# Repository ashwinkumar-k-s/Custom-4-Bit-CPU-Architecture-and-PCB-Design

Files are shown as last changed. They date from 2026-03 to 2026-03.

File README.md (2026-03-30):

# Custom 4-Bit CPU Architecture and PCB Design

Designed and simulated a 4-bit microprocessor datapath using discrete logic, including an ALU, program counter, and memory units. Created full schematic and PCB layouts for all individual modules using KiCad, and successfully fabricated and tested the physical ALU board.

## System Architecture

This project implements a rudimentary discrete logic 4-bit processor datapath. The architecture is modularly designed, consisting of the following key components:

### Program Counter (PC)
* 2 Bit Counter using D-Flip Flop to cycle between 4 instructions

### Instruction Memory
* A network of 8 4x1 MUXs to obtain an instruction of 8 bit wide and have 4 instructions at a time loaded.
 8x4_instruction_memory

### 4x4 Memory Unit
* Consists of 4 2x4 Decoders, 4 4-Bit Registers and 4 4x1 MUXs.
* 2x4 Decoder : Used to load values into the register, controlled using Enable signals while in write mode.
* 4-Bit Register: Receives data from Decoders, interconnected as, all Bit-0s from decoder to Register-1, all Bit-1s from decoder to Register-2, all Bit-2s from decoder to Register-3, all Bit-3s from decoder to Register-4.
* 4x1 MUX: Used to read data from the register when in read mode, similar interconnect network as instruction memory.
  4x4_memory_unit

### Operand controller
* Complementary pair of Tri-State Buffers connected to both Registers containing operand A and B
  operand selector

### Arithmetic Logic Unit (ALU)
* Could do 7 operations AND, OR, XOR, ADD, SUB, ROR, ROL.
* AND, OR, XOR operations are directly computed from the received inputs directly using dedicated ICs.
* ADD and SUB is done in a single circuit consisting of 2 Full adders and a XOR IC, where ADD = A+B and SUB = A + 2's complement(B).
* Rotate operations ROR (right) and ROL (left) is done with a 4-bit barrel shifter(used to shift in a single clock cycle).
  4_bit_alu

### Output Control Unit
* All the outputs are simultaneouslly calculated in the ALU,
* Each output is 4-Bit wide and is connected to a dedicated set of 4-Bit Tri-state buffers controlled using a 3x8 Decoder to output the desired value.
  <br>
  output_control_unit

---

## Tools & Technologies

* **Logic Simulation:** Cedar Logic
* **Schematic Capture & PCB Layout:** KiCad
* **Hardware:** Discrete logic ICs, custom fabricated PCB

---

## Hardware Implementation & PCB Design

All functional modules were modeled, schematized, and routed as individual PCBs. The ALU module was fabricated in PCB and the rest were validated in breadboard circuitry.

### Hardware implementation of 4x4 Memory unit 

<br>

* 4 4x1 MUXs - 74LS153.
* 4 4-Bit Registers - 74LS173.
* 4 2x4 Decoder - 74LS139.
<br>


<br>

### Hardware implementation of Memory Data Register (Operand Selector)

<br>

* 3 4-Bit Registers - 74LS173.
* 1 8xTri-State Buffers - 74LS244.
* 1x2 Decoder made using AND and NOT ICs.

### ALU implementaion in PCB
alu pcb_re
<br>

* AND - 7408.
* OR - 7432.
* XOR - 7486.
* 4-Bit Full Adder - 7483.
* 4x1 MUX - 74153.
<br>


<br>

### Output Control Unit
output control
<br>

* 3x8 Decoder - 74138.
* 7 4-Bit Registers - 74173.
<br>

alu_full

<br>

### KiCad PCB Layouts

<br>


<br>

* PCB Layout of Memory Unit
<br>


<br>


<br>

* PCB layout of ALU
<br>


<br>


<br>

* PCB layout of Output Control Unit

### Cedar Logic Simulation
4-bit cpu
<br>

---

## Repository Structure

```text
├── simulations/          # Cedar Logic simulation files
│   ├── full_layout 
├── kicad_projects/       # KiCad schematics and PCB layout files
│   ├── Output_control_unit/
│   ├── ALU_module/
│   └── 4x4_Memory_Unit/     
└── README.md
 ```

## Contributors

This 4-bit CPU architecture and PCB design project was collaboratively developed as an assigned group project. 

* **[Adithya Balesh (CB.EN.U4ECE23005)/adithyabalesh]** - *Digital Design and Hardware Verification and PCB*
  * Instruction Memory and Component Integration and verification.
  * Hardware Implementation of Output control unit and ALU.
  * PCB routing and layout arrangement of memory.
  * Poster and Documentation.

* **[Ashwin Kumar K S (CB.EN.U4ECE23007)/ashwinkumar-k-s]** - *ALU Design and PCB routing,hardware impllementaion*
  * ALU, Output Control Unit and Datapath design.
  * Component Selection and Hardware implementation of ALU and Memory data register.
  * PCB routing, layout, and schematic generation of ALU and Output control Unit 
  * Documentation and Github Repo Creation.
  
* **[Chokkalingam S (CB.EN.U4ECE23012)/-------]** - *Memory Design and hardware impllementaion*
  * Digital design of 4x4 Memory Unit,  Memory Data Register Design and Pipeline/Interconnects accross all modules.
  * Hardware implementation and verification of Memory module and Instruction Memory.
  * PCB schematic of Memory module.
  * Documentation.

* **[Rohith J (CB.EN.U4ECE23017)/-------]** - *Digital Design and Hardware Verification*
  * Digital design verification of all components.
  * Hardware circuit implementation of and Memory Units.
  * PCB schematic verification and soldering.
  * Poster, Presentation and Documentation

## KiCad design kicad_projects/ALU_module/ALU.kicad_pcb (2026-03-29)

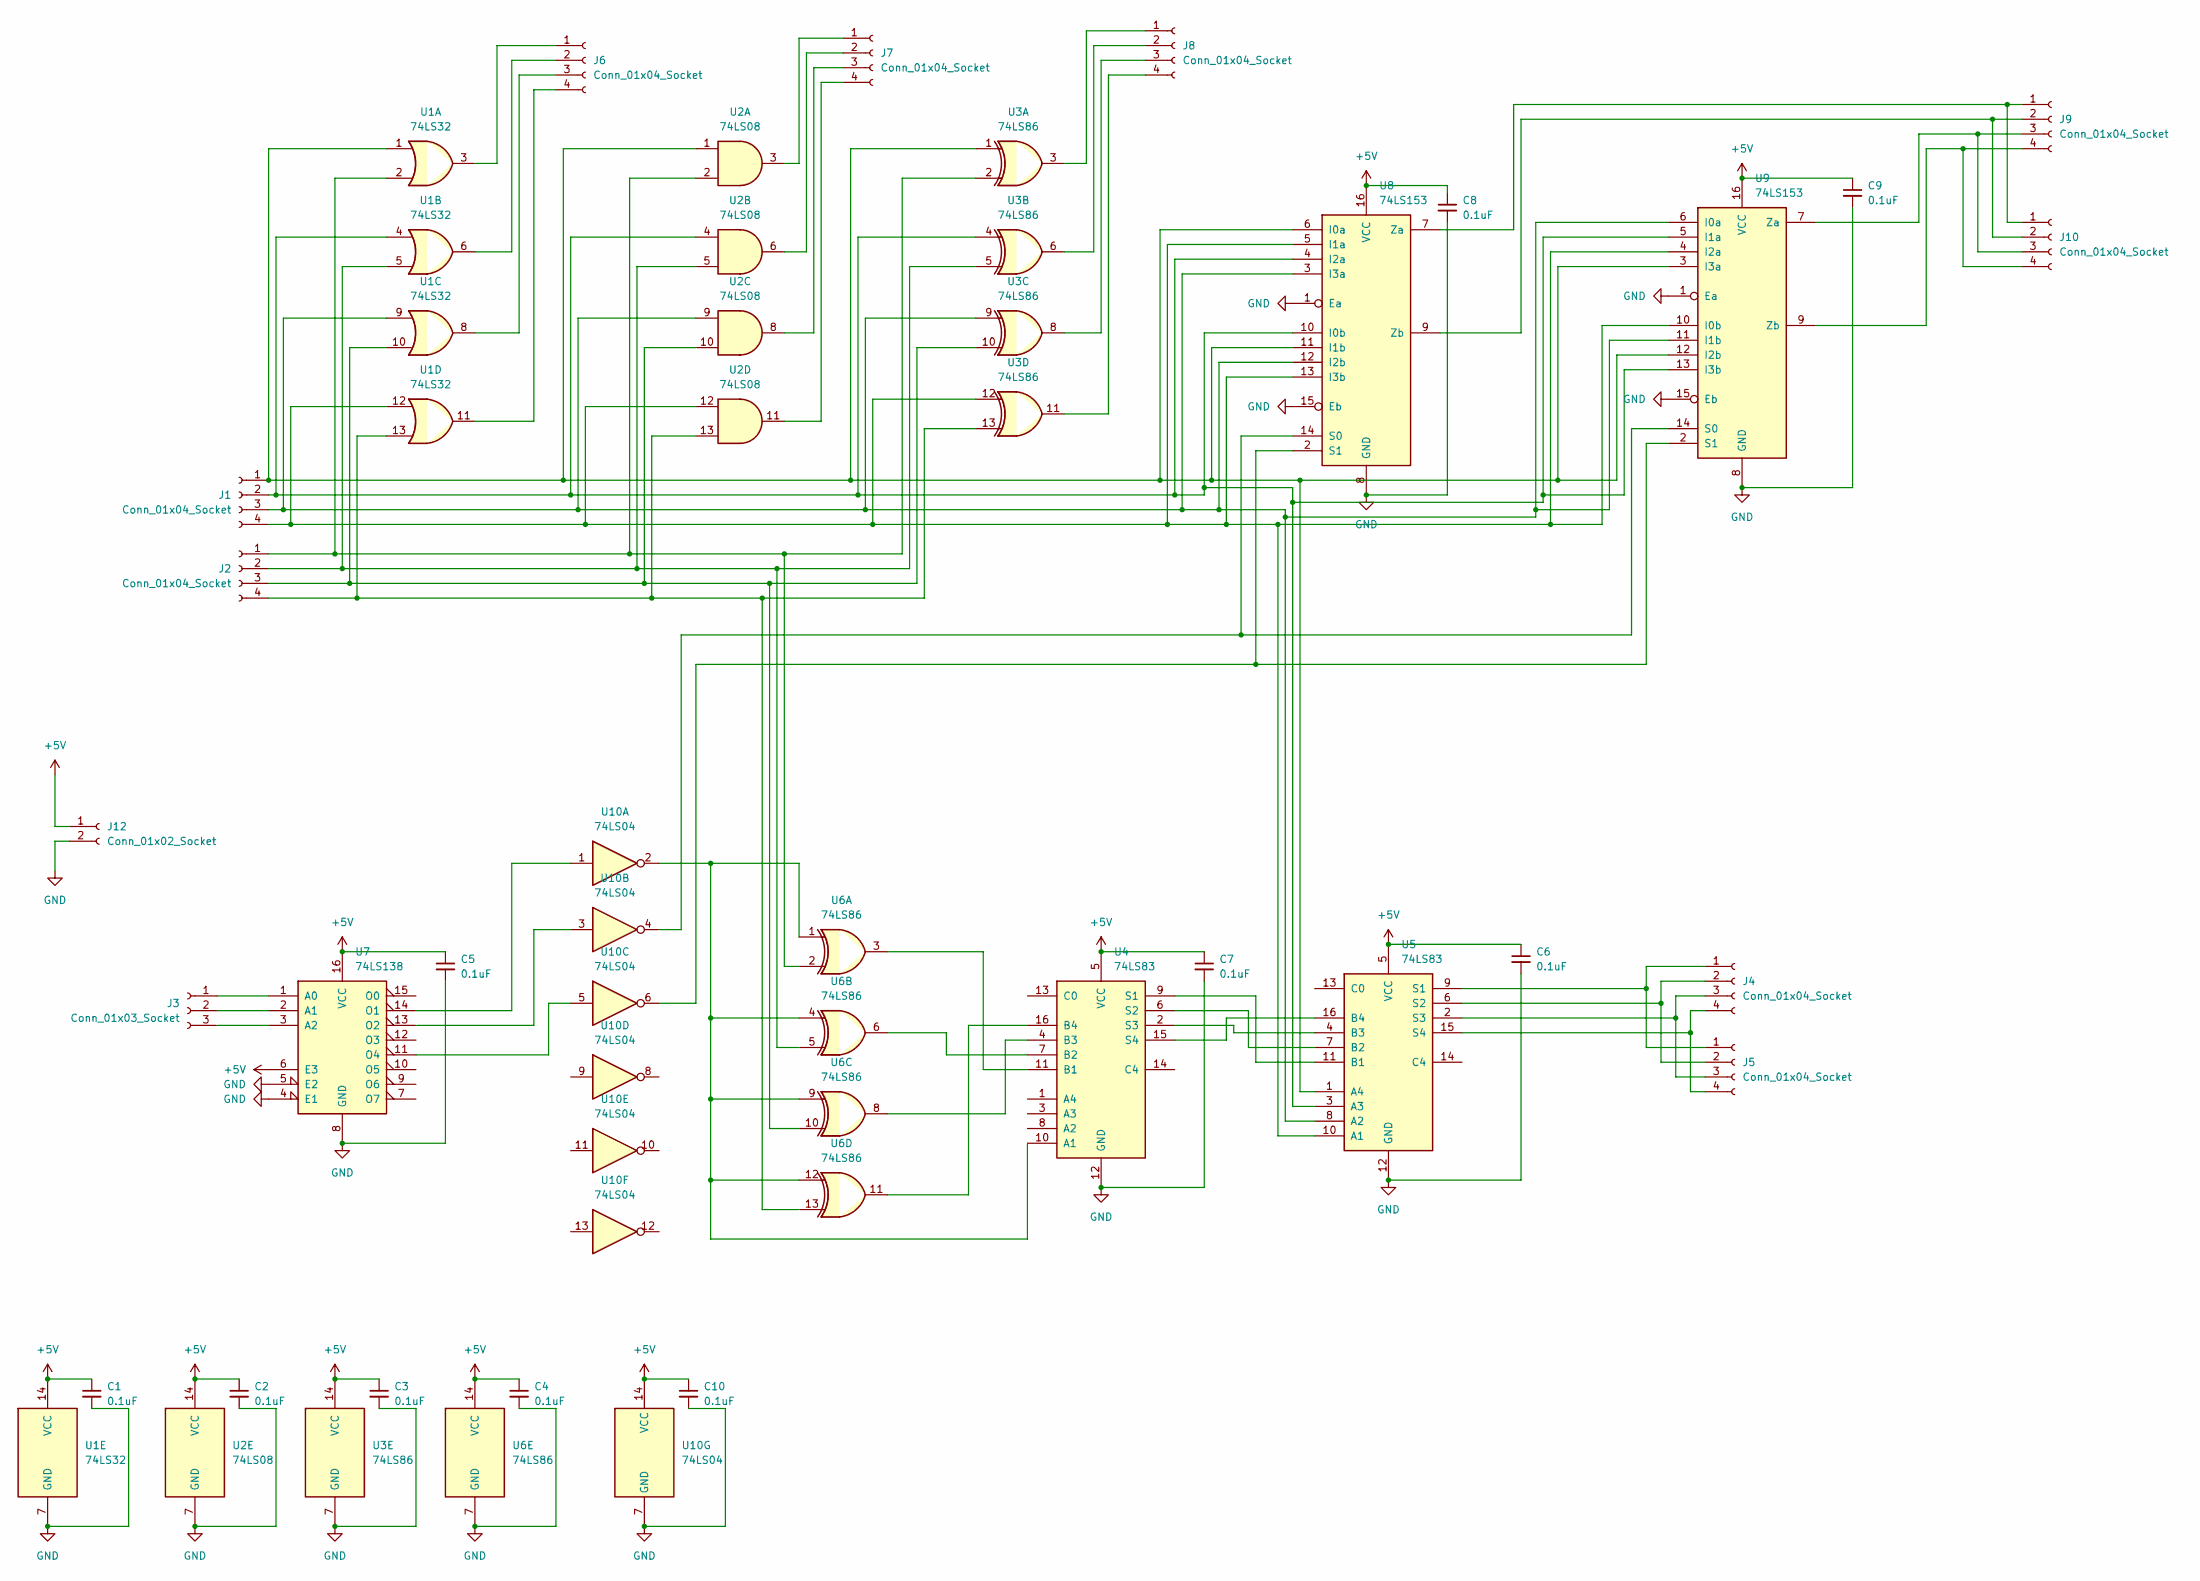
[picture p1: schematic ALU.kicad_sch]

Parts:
C1, C2, C3, C4, C5, C6, C7, C8, C9, C10: 0.1uF; C_Disc_D5.0mm_W2.5mm_P2.50mm
J1, J2, J4, J5, J6, J7, J8, J9, J10: Conn_01x04_Socket; PinSocket_1x04_P2.54mm_Vertical
J3: Conn_01x03_Socket; PinSocket_1x03_P2.54mm_Vertical
J12: Conn_01x02_Socket; PinSocket_1x02_P2.54mm_Vertical
U1: 74LS32; DIP-14_W7.62mm_LongPads
U2: 74LS08; DIP-14_W7.62mm_LongPads
U3, U6: 74LS86; DIP-14_W7.62mm_LongPads
U4, U5: 74LS83; DIP-16_W7.62mm_LongPads
U7: 74LS138; DIP-16_W7.62mm_LongPads
U8, U9: 74LS153; DIP-16_W7.62mm_LongPads
U10: 74LS04; DIP-14_W7.62mm_LongPads

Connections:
+5V: C1.1, C2.1, C3.1, C4.1, C5.1, C6.1, C7.1, C8.1, C9.1, C10.1, J12.1, U1.14 (VCC), U2.14 (VCC), U3.14 (VCC), U4.5 (VCC), U5.5 (VCC), U6.14 (VCC), U7.6 (E3), U7.16 (VCC), U8.16 (VCC), U9.16 (VCC), U10.14 (VCC)
GND: C1.2, C2.2, C3.2, C4.2, C5.2, C6.2, C7.2, C8.2, C9.2, C10.2, J12.2, U1.7 (GND), U2.7 (GND), U3.7 (GND), U4.12 (GND), U5.12 (GND), U6.7 (GND), U7.4 (E1), U7.5 (E2), U7.8 (GND), U8.1 (Ea), U8.8 (GND), U8.15 (Eb), U9.1 (Ea), U9.8 (GND), U9.15 (Eb), U10.7 (GND)
unnamed: J1.1, U1.1, U2.1, U3.1, U5.1 (A4), U8.6 (I0a), U8.11 (I1b), U9.3 (I3a), U9.12 (I2b)
unnamed: J1.2, U1.4, U2.4, U3.4, U5.3 (A3), U8.4 (I2a), U8.10 (I0b), U9.5 (I1a), U9.13 (I3b)
unnamed: J1.3, U1.9, U2.9, U3.9, U5.8 (A2), U8.3 (I3a), U8.12 (I2b), U9.6 (I0a), U9.11 (I1b)
unnamed: J1.4, U1.12, U2.12, U3.12, U5.10 (A1), U8.5 (I1a), U8.13 (I3b), U9.4 (I2a), U9.10 (I0b)
unnamed: J2.1, U1.2, U2.2, U3.2, U6.2
unnamed: J2.2, U1.5, U2.5, U3.5, U6.5
unnamed: J2.3, U1.10, U2.10, U3.10, U6.10
unnamed: J2.4, U1.13, U2.13, U3.13, U6.13
unnamed: J3.1, U7.1 (A0)
unnamed: J3.2, U7.2 (A1)
unnamed: J3.3, U7.3 (A2)
unnamed: J4.1, J5.1, U5.9 (S1)
unnamed: J4.2, J5.2, U5.6 (S2)
unnamed: J4.3, J5.3, U5.2 (S3)
unnamed: J4.4, J5.4, U5.15 (S4)
unnamed: J6.1, U1.3
unnamed: J6.2, U1.6
unnamed: J6.3, U1.8
unnamed: J6.4, U1.11
unnamed: J7.1, U2.3
unnamed: J7.2, U2.6
unnamed: J7.3, U2.8
unnamed: J7.4, U2.11
unnamed: J8.1, U3.3
unnamed: J8.2, U3.6
unnamed: J8.3, U3.8
unnamed: J8.4, U3.11
unnamed: J9.1, J10.1, U8.7 (Za)
unnamed: J9.2, J10.2, U8.9 (Zb)
unnamed: J9.3, J10.3, U9.7 (Za)
unnamed: J9.4, J10.4, U9.9 (Zb)
unnamed: U4.10 (A1), U6.1, U6.4, U6.9, U6.12, U10.2
unnamed: U4.11 (B1), U6.3
unnamed: U4.7 (B2), U6.6
unnamed: U4.4 (B3), U6.8
unnamed: U4.16 (B4), U6.11
unnamed: U4.9 (S1), U5.11 (B1)
unnamed: U4.6 (S2), U5.7 (B2)
unnamed: U4.2 (S3), U5.4 (B3)
unnamed: U4.15 (S4), U5.16 (B4)
unnamed: U7.14 (O1), U10.1
unnamed: U7.13 (O2), U10.3
unnamed: U7.11 (O4), U10.5
unnamed: U8.14 (S0), U9.14 (S0), U10.4
unnamed: U8.2 (S1), U9.2 (S1), U10.6

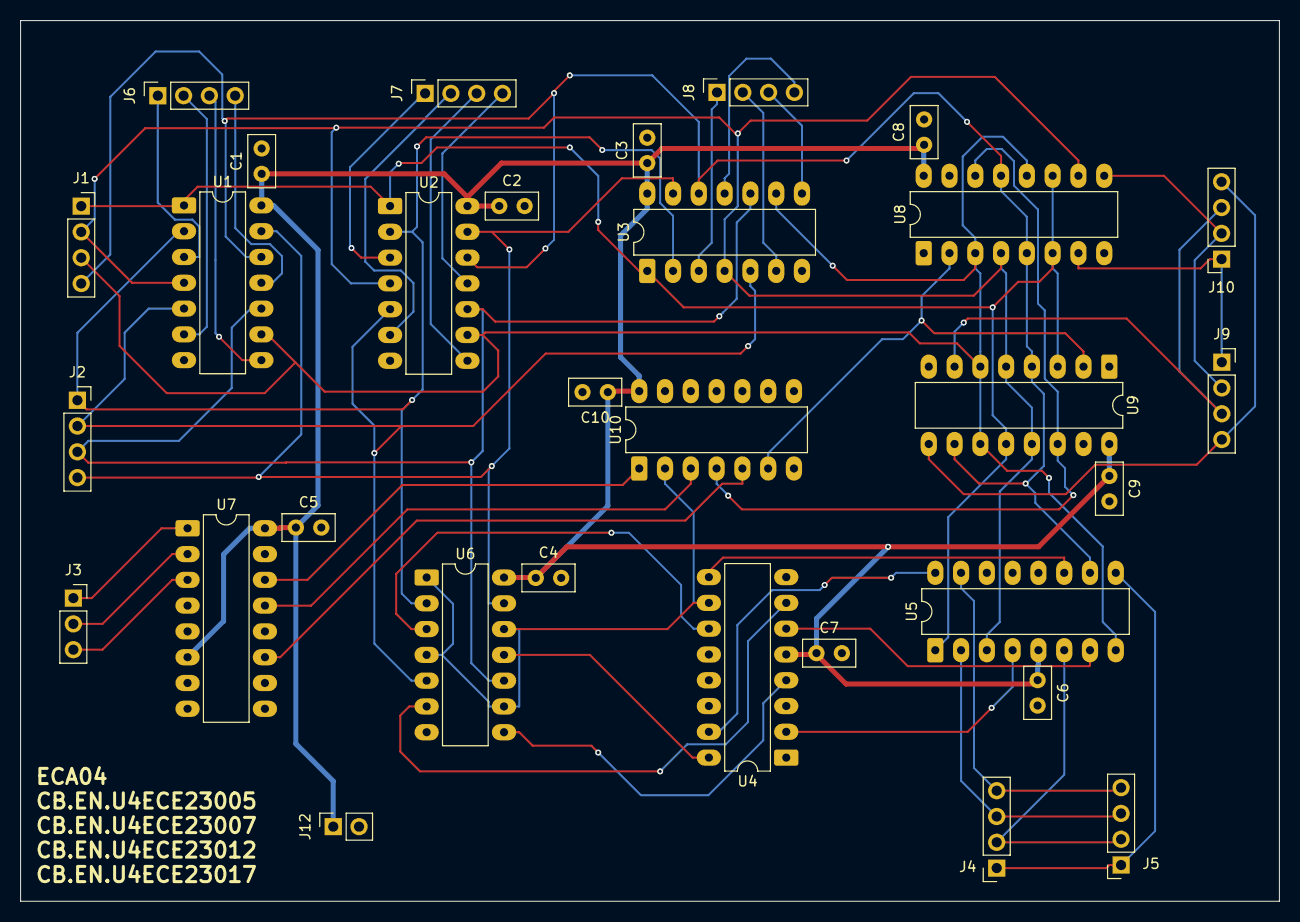
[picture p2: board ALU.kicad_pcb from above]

Board: 2 copper layers, 124.0 x 86.8 mm, 31 parts (0 on the bottom side), 47 nets.

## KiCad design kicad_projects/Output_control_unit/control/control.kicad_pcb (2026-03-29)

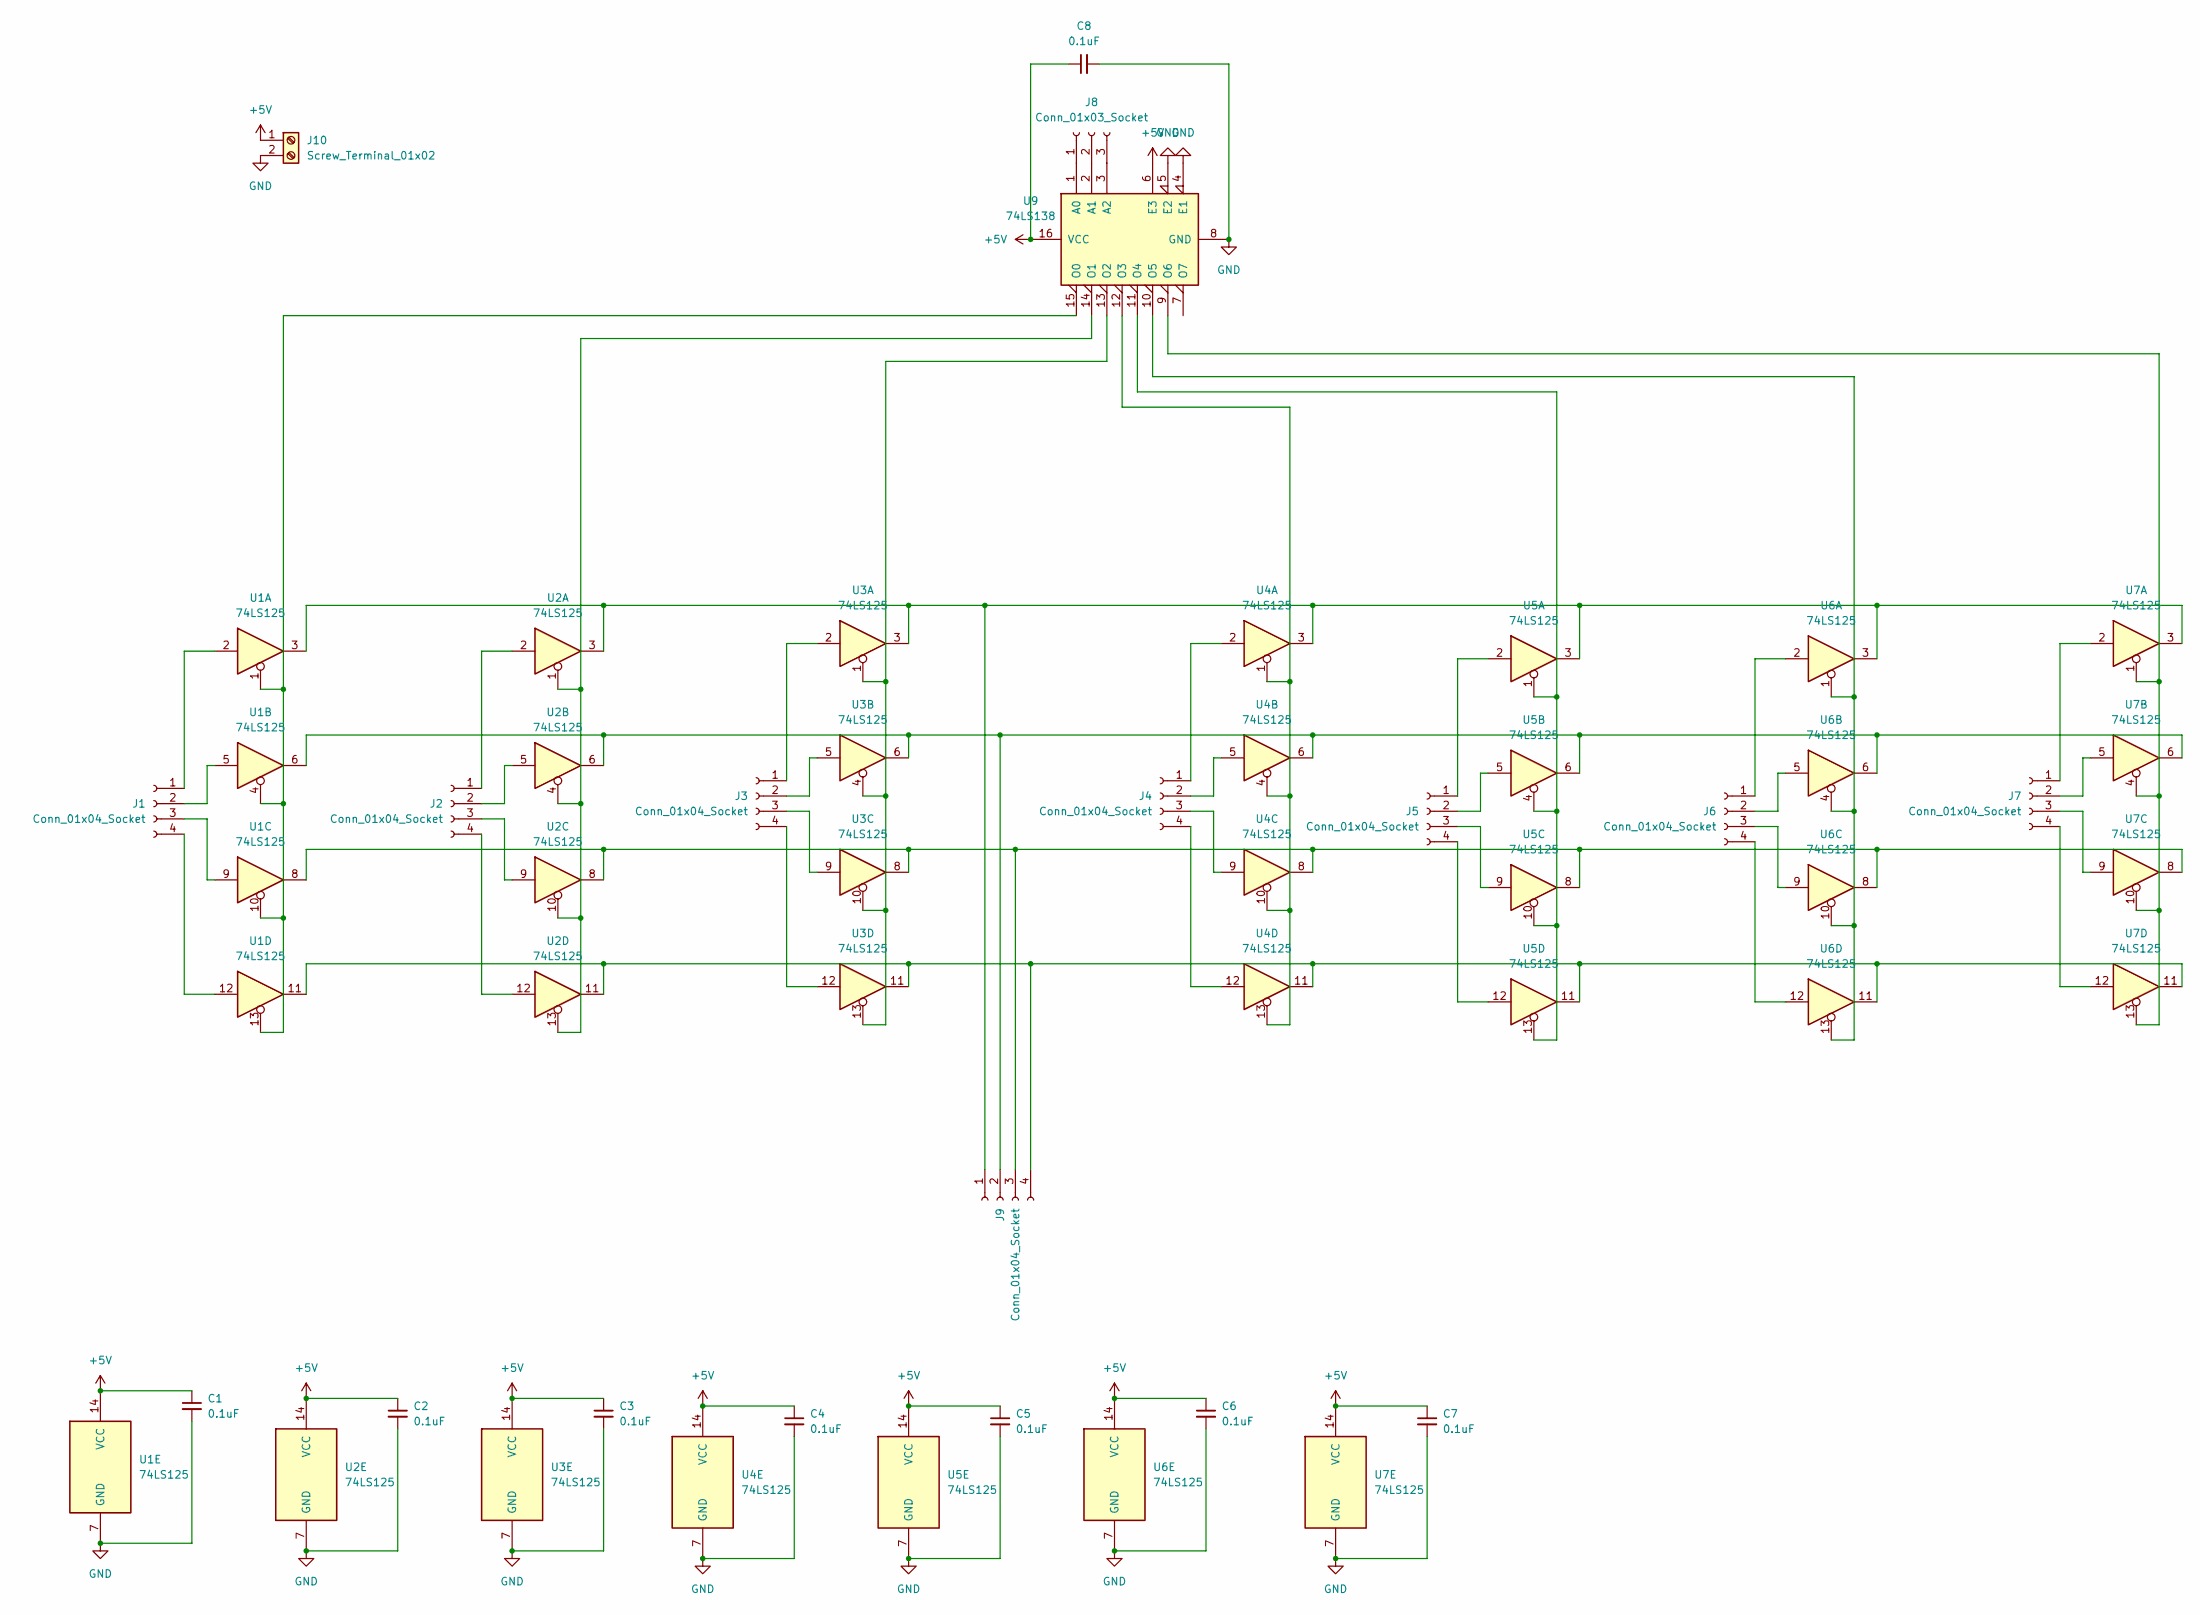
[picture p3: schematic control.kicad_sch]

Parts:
C1, C2, C3, C4, C5, C6, C7, C8: 0.1uF; C_Disc_D5.0mm_W2.5mm_P2.50mm
J1, J2, J3, J4, J5, J6, J7, J9: Conn_01x04_Socket; PinSocket_1x04_P2.54mm_Vertical
J8: Conn_01x03_Socket; PinSocket_1x03_P2.54mm_Vertical
J10: Screw_Terminal_01x02; TerminalBlock_MetzConnect_Type094_RT03502HBLU_1x02_P5.00mm_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
U1, U2, U3, U4, U5, U6, U7: 74LS125; DIP-14_W7.62mm_LongPads
U9: 74LS138; DIP-16_W7.62mm_LongPads

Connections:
+5V: C1.1, C2.1, C3.1, C4.1, C5.1, C6.1, C7.1, C8.1, J10.1, U1.14 (VCC), U2.14 (VCC), U3.14 (VCC), U4.14 (VCC), U5.14 (VCC), U6.14 (VCC), U7.14 (VCC), U9.6 (E3), U9.16 (VCC)
GND: C1.2, C2.2, C3.2, C4.2, C5.2, C6.2, C7.2, C8.2, J10.2, U1.7 (GND), U2.7 (GND), U3.7 (GND), U4.7 (GND), U5.7 (GND), U6.7 (GND), U7.7 (GND), U9.4 (E1), U9.5 (E2), U9.8 (GND)
unnamed: J1.1, U1.2
unnamed: J1.2, U1.5
unnamed: J1.3, U1.9
unnamed: J1.4, U1.12
unnamed: J2.1, U2.2
unnamed: J2.2, U2.5
unnamed: J2.3, U2.9
unnamed: J2.4, U2.12
unnamed: J3.1, U3.2
unnamed: J3.2, U3.5
unnamed: J3.3, U3.9
unnamed: J3.4, U3.12
unnamed: J4.1, U4.2
unnamed: J4.2, U4.5
unnamed: J4.3, U4.9
unnamed: J4.4, U4.12
unnamed: J5.1, U5.2
unnamed: J5.2, U5.5
unnamed: J5.3, U5.9
unnamed: J5.4, U5.12
unnamed: J6.1, U6.2
unnamed: J6.2, U6.5
unnamed: J6.3, U6.9
unnamed: J6.4, U6.12
unnamed: J7.1, U7.2
unnamed: J7.2, U7.5
unnamed: J7.3, U7.9
unnamed: J7.4, U7.12
unnamed: J8.1, U9.1 (A0)
unnamed: J8.2, U9.2 (A1)
unnamed: J8.3, U9.3 (A2)
unnamed: J9.1, U1.3, U2.3, U3.3, U4.3, U5.3, U6.3, U7.3
unnamed: J9.2, U1.6, U2.6, U3.6, U4.6, U5.6, U6.6, U7.6
unnamed: J9.3, U1.8, U2.8, U3.8, U4.8, U5.8, U6.8, U7.8
unnamed: J9.4, U1.11, U2.11, U3.11, U4.11, U5.11, U6.11, U7.11
unnamed: U1.1, U1.4, U1.10, U1.13, U9.15 (O0)
unnamed: U2.1, U2.4, U2.10, U2.13, U9.14 (O1)
unnamed: U3.1, U3.4, U3.10, U3.13, U9.13 (O2)
unnamed: U4.1, U4.4, U4.10, U4.13, U9.12 (O3)
unnamed: U5.1, U5.4, U5.10, U5.13, U9.11 (O4)
unnamed: U6.1, U6.4, U6.10, U6.13, U9.10 (O5)
unnamed: U7.1, U7.4, U7.10, U7.13, U9.9 (O6)

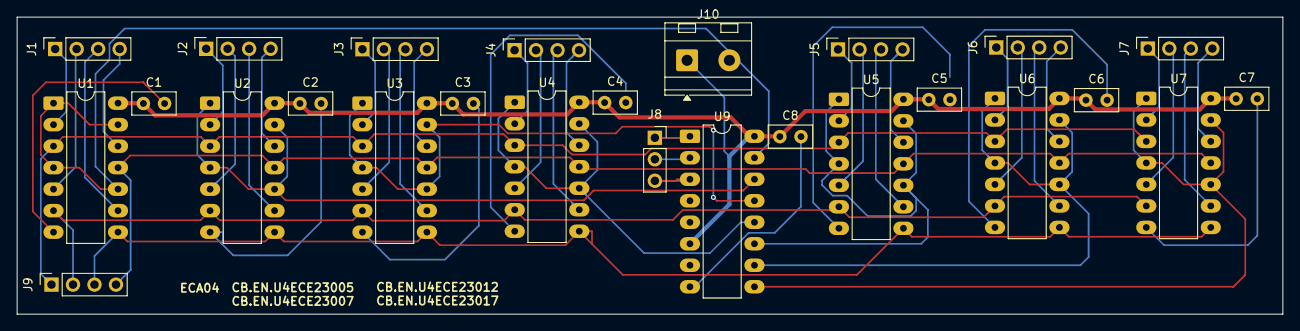
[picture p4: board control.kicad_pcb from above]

Board: 2 copper layers, 149.6 x 35.1 mm, 26 parts (0 on the bottom side), 44 nets.

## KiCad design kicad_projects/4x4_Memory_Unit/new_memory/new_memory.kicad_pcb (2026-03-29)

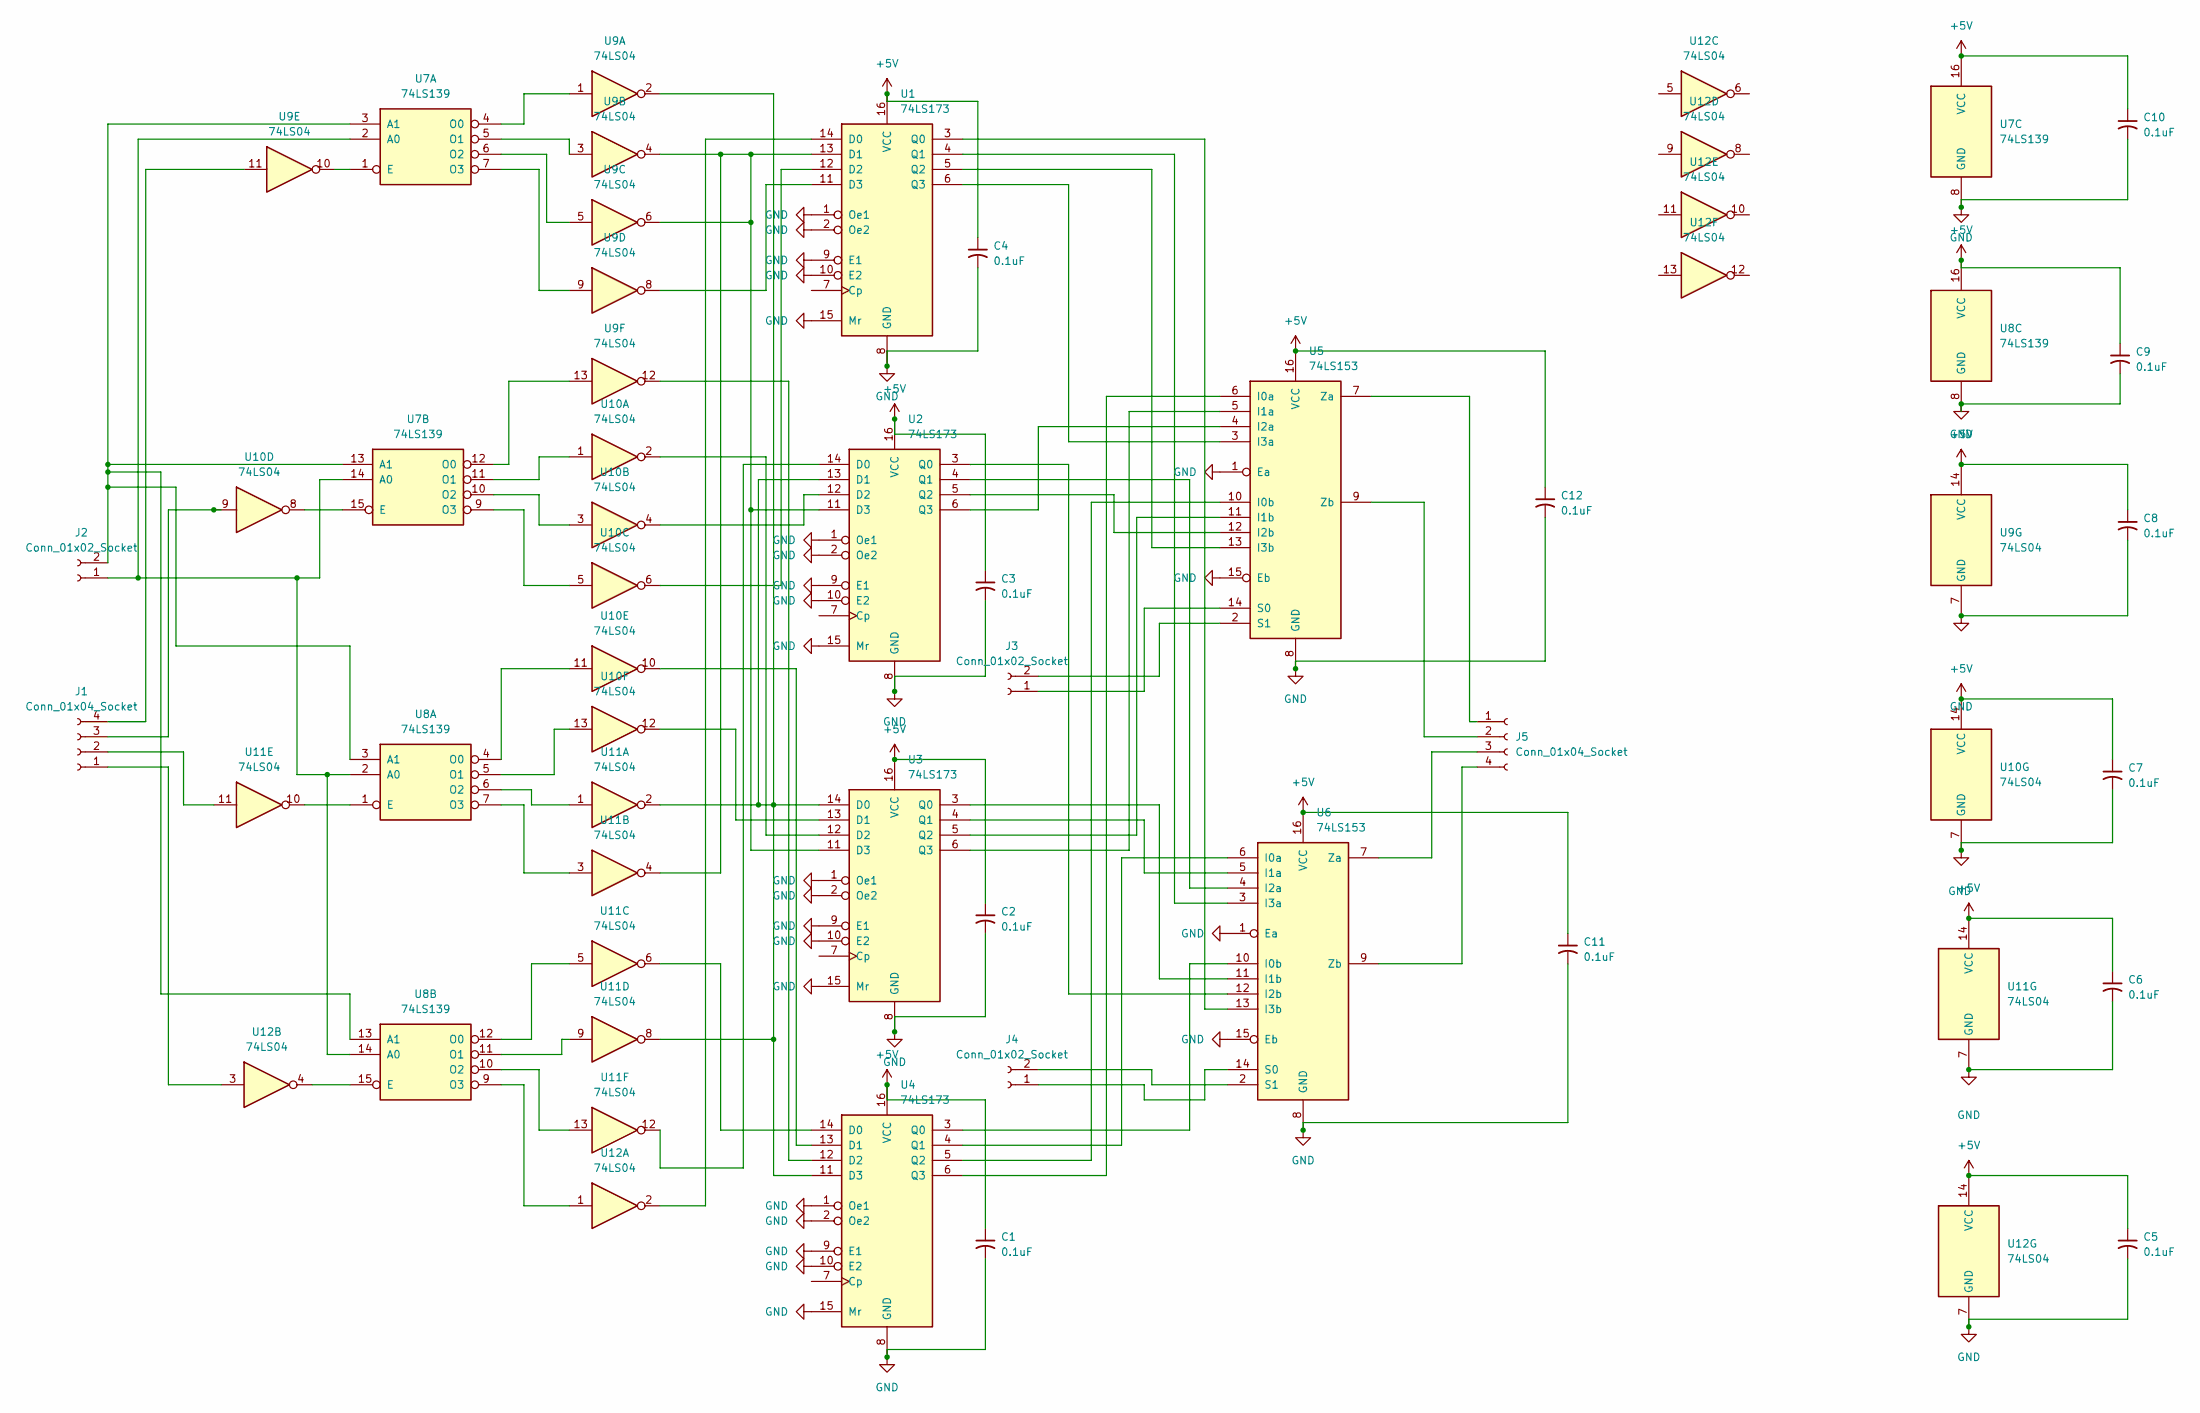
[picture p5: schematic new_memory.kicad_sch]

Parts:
C1, C2, C3, C4, C5, C6, C7, C8, C9, C10, C11, C12: 0.1uF; C_Disc_D5.0mm_W2.5mm_P2.50mm
J1: Conn_01x04_Socket; PinSocket_1x04_P2.54mm_Vertical
J2, J3, J4: Conn_01x02_Socket; PinSocket_1x02_P2.54mm_Vertical
J5: Conn_01x04_Socket
U1, U2, U3, U4: 74LS173; DIP-16_W7.62mm_LongPads
U5, U6: 74LS153; DIP-16_W7.62mm_LongPads
U7, U8: 74LS139; DIP-16_W7.62mm_LongPads
U9, U10, U11, U12: 74LS04; DIP-14_W7.62mm_LongPads

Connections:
+5V: C1.1, C2.1, C3.1, C4.1, C5.1, C6.1, C7.1, C8.1, C9.1, C10.1, C11.1, C12.1, U1.16 (VCC), U2.16 (VCC), U3.16 (VCC), U4.16 (VCC), U5.16 (VCC), U6.16 (VCC), U7.16 (VCC), U8.16 (VCC), U9.14 (VCC), U10.14 (VCC), U11.14 (VCC), U12.14 (VCC)
GND: C1.2, C2.2, C3.2, C4.2, C5.2, C6.2, C7.2, C8.2, C9.2, C10.2, C11.2, C12.2, U1.1 (Oe1), U1.2 (Oe2), U1.8 (GND), U1.9 (E1), U1.10 (E2), U1.15 (Mr), U2.1 (Oe1), U2.2 (Oe2), U2.8 (GND), U2.9 (E1), U2.10 (E2), U2.15 (Mr), U3.1 (Oe1), U3.2 (Oe2), U3.8 (GND), U3.9 (E1), U3.10 (E2), U3.15 (Mr), U4.1 (Oe1), U4.2 (Oe2), U4.8 (GND), U4.9 (E1), U4.10 (E2), U4.15 (Mr), U5.1 (Ea), U5.8 (GND), U5.15 (Eb), U6.1 (Ea), U6.8 (GND), U6.15 (Eb), U7.8 (GND), U8.8 (GND), U9.7 (GND), U10.7 (GND), U11.7 (GND), U12.7 (GND)
unnamed: J1.1, U12.3
unnamed: J1.2, U11.11
unnamed: J1.3, U10.9
unnamed: J1.4, U9.11
unnamed: J2.1, U7.2 (A0), U7.14 (A0), U8.2 (A0), U8.14 (A0)
unnamed: J2.2, U7.3 (A1), U7.13 (A1), U8.3 (A1), U8.13 (A1)
unnamed: J3.1, U5.14 (S0)
unnamed: J3.2, U5.2 (S1)
unnamed: J4.1, U6.14 (S0)
unnamed: J4.2, U6.2 (S1)
unnamed: J5.1, U5.7 (Za)
unnamed: J5.2, U5.9 (Zb)
unnamed: J5.3, U6.7 (Za)
unnamed: J5.4, U6.9 (Zb)
unnamed: U1.14 (D0), U12.2
unnamed: U1.13 (D1), U2.11 (D3), U3.11 (D3), U9.4, U9.6, U11.4
unnamed: U1.12 (D2), U10.6
unnamed: U1.11 (D3), U9.8
unnamed: U1.3 (Q0), U6.13 (I3b)
unnamed: U1.4 (Q1), U6.3 (I3a)
unnamed: U1.5 (Q2), U5.13 (I3b)
unnamed: U1.6 (Q3), U5.3 (I3a)
unnamed: U2.14 (D0), U11.12
unnamed: U2.13 (D1), U3.14 (D0), U4.11 (D3), U9.2, U11.2, U11.8
unnamed: U2.12 (D2), U10.4
unnamed: U2.3 (Q0), U6.12 (I2b)
unnamed: U2.4 (Q1), U6.4 (I2a)
unnamed: U2.5 (Q2), U5.12 (I2b)
unnamed: U2.6 (Q3), U5.4 (I2a)
unnamed: U3.13 (D1), U10.12
unnamed: U3.12 (D2), U10.2
unnamed: U3.3 (Q0), U6.11 (I1b)
unnamed: U3.4 (Q1), U6.5 (I1a)
unnamed: U3.5 (Q2), U5.11 (I1b)
unnamed: U3.6 (Q3), U5.5 (I1a)
unnamed: U4.14 (D0), U11.6
unnamed: U4.13 (D1), U10.10
unnamed: U4.12 (D2), U9.12
unnamed: U4.3 (Q0), U6.10 (I0b)
unnamed: U4.4 (Q1), U6.6 (I0a)
unnamed: U4.5 (Q2), U5.10 (I0b)
unnamed: U4.6 (Q3), U5.6 (I0a)
unnamed: U7.1 (E), U9.10
unnamed: U7.4 (O0), U9.1
unnamed: U7.5 (O1), U9.3
unnamed: U7.6 (O2), U9.5
unnamed: U7.7 (O3), U9.9
unnamed: U7.15 (E), U10.8
unnamed: U7.12 (O0), U9.13
unnamed: U7.11 (O1), U10.1
unnamed: U7.10 (O2), U10.3
unnamed: U7.9 (O3), U10.5
unnamed: U8.1 (E), U11.10
unnamed: U8.4 (O0), U10.11
unnamed: U8.5 (O1), U10.13
unnamed: U8.6 (O2), U11.1
unnamed: U8.7 (O3), U11.3
unnamed: U8.15 (E), U12.4
unnamed: U8.12 (O0), U11.5
unnamed: U8.11 (O1), U11.9
unnamed: U8.10 (O2), U11.13
unnamed: U8.9 (O3), U12.1

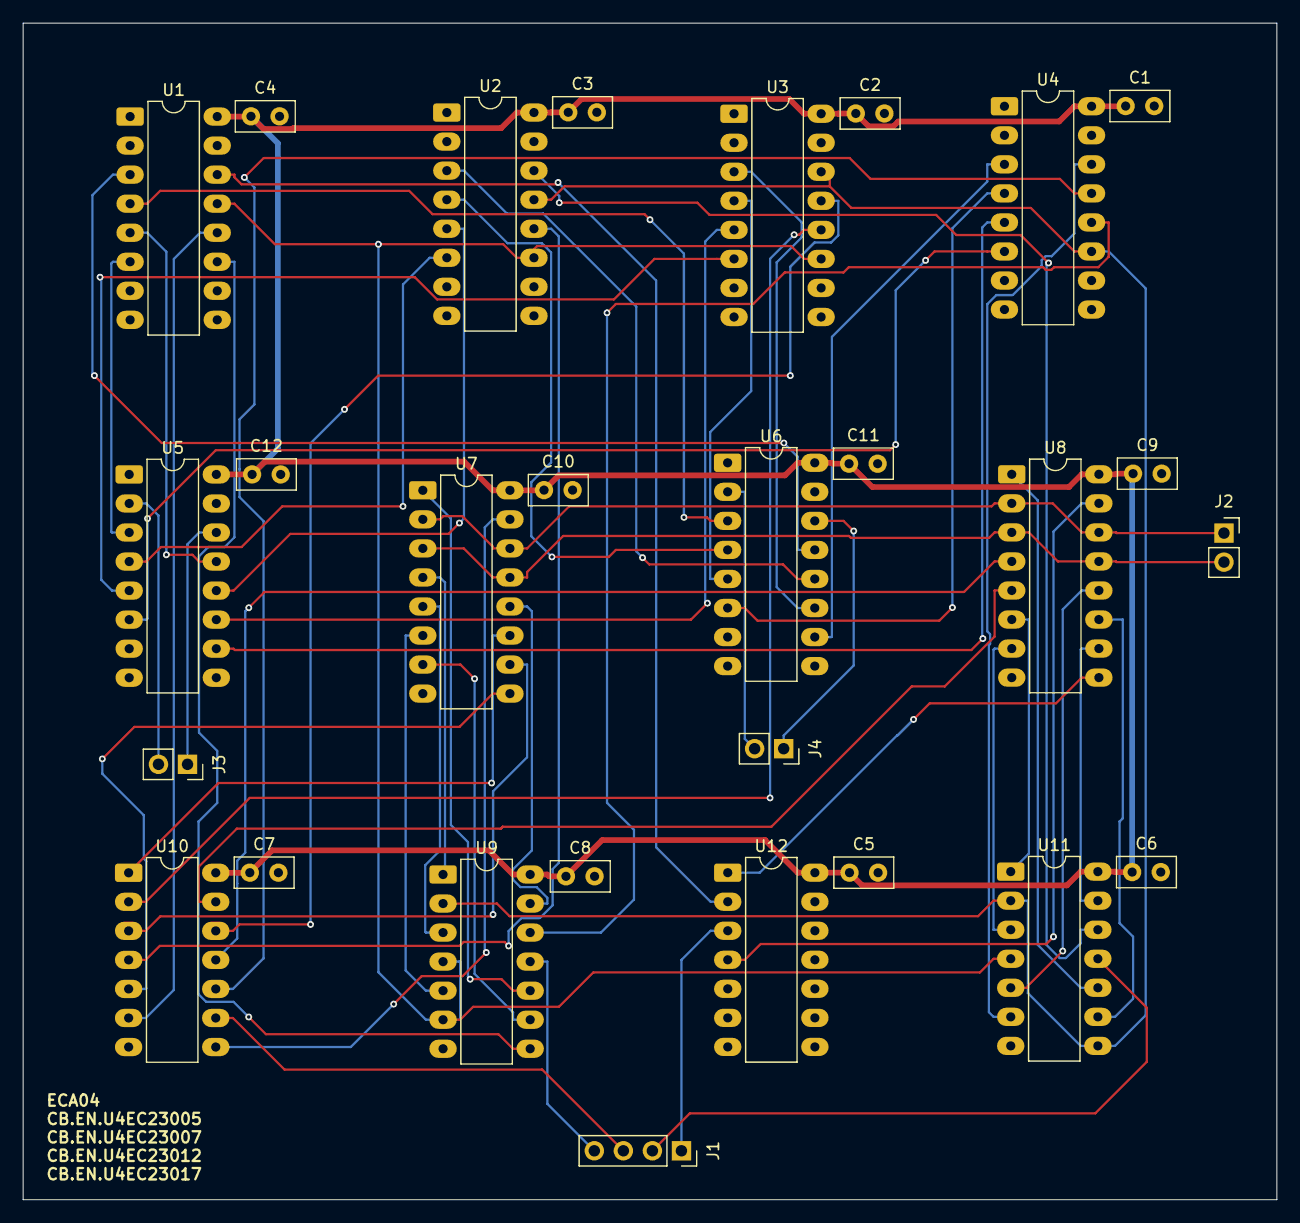
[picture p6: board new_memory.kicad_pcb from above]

Board: 2 copper layers, 109.7 x 102.9 mm, 28 parts (0 on the bottom side), 60 nets.
